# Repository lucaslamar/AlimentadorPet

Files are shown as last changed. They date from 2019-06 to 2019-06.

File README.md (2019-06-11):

# Alimentador Pet
o Alimentador Pet feito com Arduino, que é uma estrutura em que os donos podem usá-la para alimentar seus animais domésticos pelo celular via Bluetooth, onde este alcançar.

OBS: Trabalho para conclusão da materia: "Tópicos Avançados em Análise e Desenvolvimento de Sistemas(Arduino)" da Faculdade Projeção Sobradinho. Mudanças ou sugestões são bem vindas.

INTEGRANTES: 

<ul>
    <li>AQUILES DIAS
    <li> GABRIELLE LIMA FERREIRA
    <li> JHONNY CARVALHO ALVES
    <li> LUCAS LAMAR DA SILVA CARNEIRO
    <li> CAIO FERNANDO SILVA OLIVEIRA
</ul> <br />

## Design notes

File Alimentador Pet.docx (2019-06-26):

FACULDADE PROJEÇÃO

Tecnologia em Análise e Desenvolvimento de Sistemas

AQUILES DIAS DE SOUSA

CAIO FERNANDO SILVA OLIVEIRA

GABRIELLE LIMA FERREIRA

JHONNY CARVALHO ALVES

LEONARDO PEREIRA DA SILVA

LUCAS LAMAR DA SILVA CARNEIRO

ALIMENTADOR PET

Brasília, junho de 2019.

FACULDADE PROJEÇÃO

Tecnologia em Análise e Desenvolvimento de Sistemas

TEMA

Tópicos Avançados em Análise e Desenvolvimento de Sistemas apresentado ao Curso de Tecnologia em Análise e Desenvolvimento de Sistemas da Faculdade Projeção.

Brasília, ___ de __________ de [ano].

Banca Examinadora:

Professor(a) :[Informar o nome completo]

Orientador(a)

Professor(a) :[Informar o nome completo]

Professor(a) : [Informar o nome completo]

Professor Rosa Maria Diekn de Queiroz, Especialista

Coordenadora do curso de Sistemas de Informação

# LISTA DE ABREVIATURAS E SIGLAS

GND Ground

ABS Acrylonitrile Butadiene Styrene

SRAM Static Random Access Memory

EEPROM Electrically Erasable Programmable Read Only Memory

AWG American Wire Gauge

VDC Voltage Direct Current

AVR Automatic Voltage Regulator

PIC Peripherical Interface Controller

TTL Transistor-transistor logic

LED Light Emitting Diode

ISM Industrial Sientific and Medical

GFSK Gaussian Freguency Shift Keying

EMI Eletromagnetic Interference

# LISTA DE FIGURA

# LISTA DE TABELAS

# RESUMO

Este documento será relatado sobre o Alimentador Pet feito com Arduino, que é uma estrutura em que os donos podem usá-la para alimentar seus animais domésticos pelo celular via Bluetooth, onde este alcançar. Serão mostradas todas as etapas do desenvolvimento dele, como o objetivo, a descrição de cada item utilizado, cronograma, protótipos, entre outros.

Palavras-Chave: Alimentador Pet, Arduino.

# ABSTRACT

This document will be reported on the Pet Feeder made with Arduino, which is a framework in which owners can use it to feed their pets via their cell phone via Bluetooth wherever it reaches. It will show all the stages of its development, such as the objective, the description of each item used, schedule, prototypes, among others.

Keywords: Pet Feeder, Arduino.

# CAPÍTULO I

# VISÃO INICIAL

## 1. INTRODUÇÃO

Atualmente, a maioria das pessoas possui um animal de estimação (cães e gatos) em casa, onde elas cuidam e os alimentam diariamente, esses animais estão se tornando cada vez mais presente em todas as famílias. Atualmente no Brasil tem 52 milhões de cães e 22 milhões de gatos espalhados pelo país (IBGE, 2013). O Alimentador Pet feito com Arduino serve para deixar de forma mais simples e prática essa alimentação, pois o dono pode fazer isso automaticamente, usando um aplicativo no seu celular e assim a estrutura libera a ração para o seu animal comer. Dessa forma, o dono não precisa se preocupar com o horário, pois é só agendar no aplicativo a hora certa para alimentá-los, quando o celular estiver conectado via Bluetooth ele só irá precisar ativar para a ração cair.

O objetivo do projeto foi alcançado e o protótipo desenvolvido indicando que o Arduino pode ser utilizado para várias aplicações que podem simplificar tarefas quotidianas

## 2. Contextualização

O Arduino foi criado em 2005 e a busca por ele vem crescendo a cada dia. É uma plataforma de prototipagem (https://pt.wikipedia.org/wiki/Prot%C3%B3tipo) eletrônica de hardware livre (https://pt.wikipedia.org/wiki/Hardware_livre) e de placa única (https://pt.wikipedia.org/wiki/Computadores_de_placa_%C3%BAnica), é fácil de usar, tem baixo custo e pode ser levado a qualquer lugar devido ao seu tamanho ser pequeno. E ele pode ser usado para controlar e automatizar várias coisas.

Com essa facilidade no uso, o Alimentador Pet será feito com ele, para ser automatizado e tornar mais fácil para os donos a alimentação de seus animais domésticos.

## 3. Problemática

Alguns donos muitas vezes se esquecem de alimentar seu animal, pois estão ocupados fazendo outras coisas; e outros às vezes têm certa preguiça de ir e colocar a alimentação, assim o animal fica passando fome, podendo até adoecer.

## 4. Solução Proposta

Esse alimentador serve para ajudar o dono a alimentar o seu animal sem se preocupar em ir colocar a comida, podendo fazer isso automaticamente através de um aplicativo de celular.

## 5. Objetivo Geral

O objetivo geral é desenvolver um alimentador automático para animais de estimação utilizando o Arduino.

### 6. Objetivos Específicos

- Utilizar Arduino
- Mostrar detalhadamente cada ligação
- Mostrar a montagem passo a passo do projeto
- Criar estrutura.

# CAPÍTULO II

# METODOLOGIA APLICADA

## 1. Metodologia e Modelo de Desenvolvimento

A metodologia que será utilizada nesse projeto será a metodologia Ágil. A metodologia ágil é uma forma de acelerar as entregas durante o desenvolvimento de um projeto, fracionando o todo em entregas incrementais, trabalhando em times auto organizados e fazendo uso da Inteligência Coletiva, com equipes multidisciplinares, para atingir uma meta estabelecida a cada fase, até a conclusão final da entrega total do projeto.

## 2. Fundamentação teórica

- Arduino é uma plataforma de prototipagem eletrônica open source que se baseia em hardware e software flexíveis e fáceis de usar.
- Jumpers são condutores utilizados para conectar dois pontos de um circuito eletrônico.
- Protoboard de 830 pontos com ligações elétricas utilizada para montar circuitos eletrônicos sem precisar soldar os terminais, com um interruptor ao meio dela.
- Motor de passo é um tipo de motor elétrico usado quando algo tem que ser posicionado muito precisamente ou rodado de um ângulo exato.
- O módulo Relé é um módulo o qual torna realmente fácil conectar um relé a um Arduino. Ele já tem todos os componentes necessários para tal conexão, fazendo só com que você necessite conectar os cabos corretamente ao Arduino.
- O sensor de distância é um tipo de sensor que mede a distância entre um ponto de referência e um objeto desejado.
- Bluetooth é um protocolo de comunicação sem fio com baixo consumo de energia onde é possível fazer a transmissão de dados entre dispositivos. O alcance varia de 1 a 100 metros e o consumo de energia vai variar de acordo com a distância de comunicação (quanto maior a distância maior o consumo).
- A Minibomba de Água RS385 foi criada especialmente para o desenvolvimento de projetos de prototipagem, incluído automação residencial e protótipos robóticos baseados em plataformas microcontroladores, entre elas, Arduino e Raspberry Pi.
- O driver de motor de passo permite o Arduino controlar motores com correntes superiores a 50mA.
- A fonte de alimentação é um componente de aparelhos eletrônicos que tem como função transformar a energia elétrica que chega pelas tomadas em uma corrente elétrica contínua. Ou seja, ela recebe a energia em 110V ou 220V e transforma na voltagem adequada para o funcionamento do aparelho, que geralmente é 12V.

## 3. Montagem do Hardware

## 3. 1 Protótipo da Modelagem do Circuito

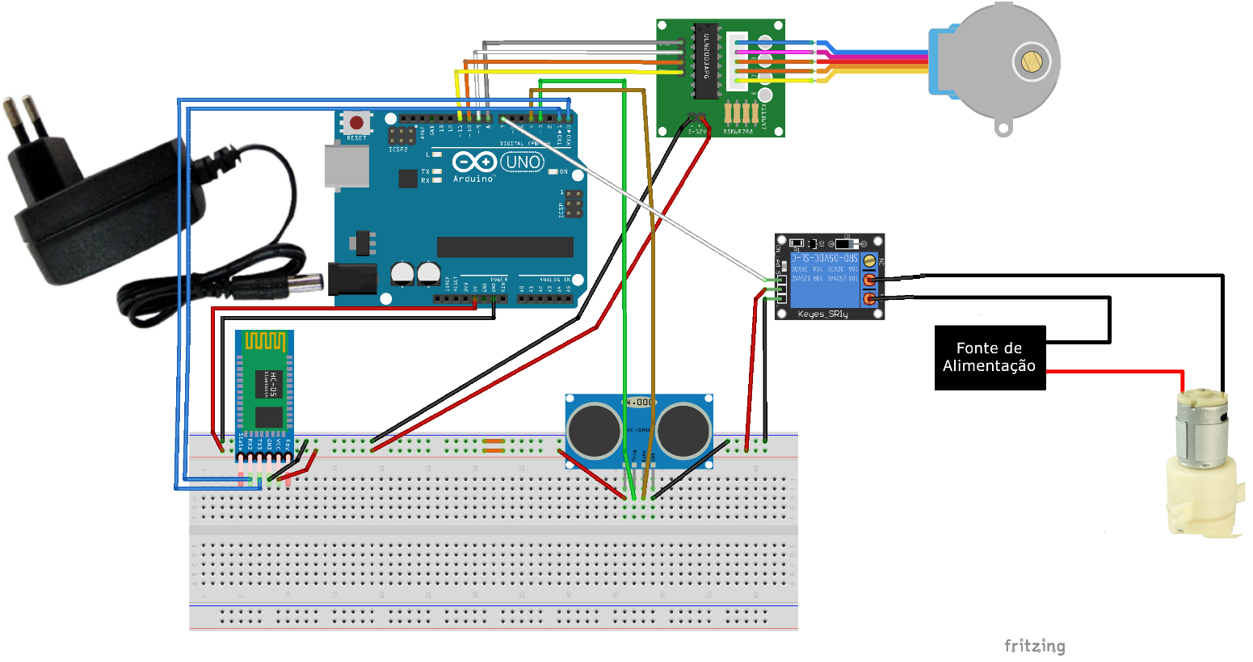
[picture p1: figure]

Figura 1 Modelagem do circuito

## 3.2 Especificação e Detalhamento dos itens utilizados

A placa Arduino costuma ser a primeira opção de muitos, ela seleciona automaticamente a fonte de alimentação (USB ou fonte externa). Ela se diferencia das outras por não utilizar o chip da FTDI USB-to-Serial. Ao invés deste chip, um Atmega8U2 já programado faz a função de converter os dados da USB para Serial.

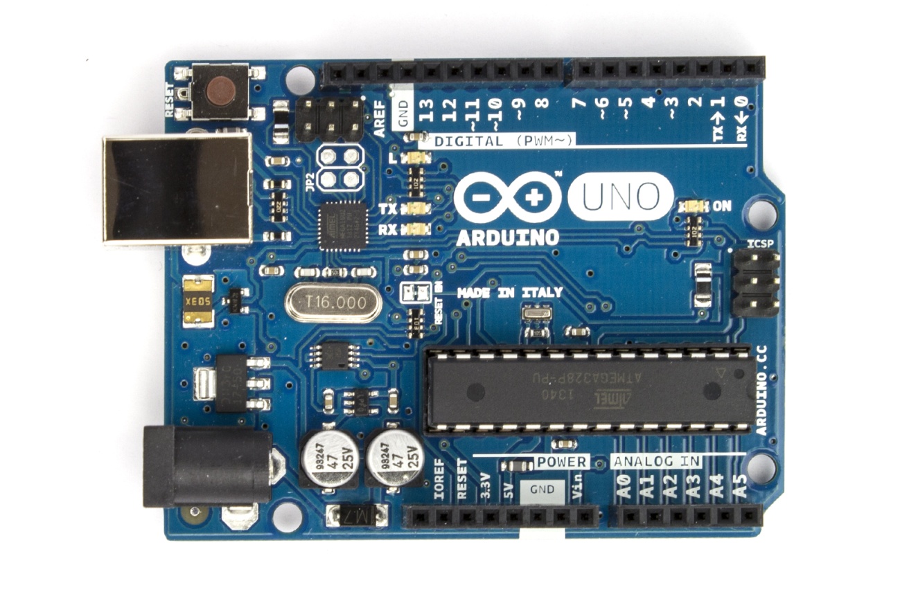
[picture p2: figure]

Figura 2 Placa Arduino Uno

- Microcontrolador: Atmega328
- Tensão de Operação: 5V
- Tensão de Entrada: 7-12V
- Portas Digitais: 14
- Portas Analógicas: 6
- Corrente Pinos I/O: 40mA
- Corrente Pinos 3,3V: 50mA
- Memória Flash: 32KB (0,5KB usado no bootloader)
- SRAM: 2KB
- EEPROM: 1KB
- Velocidade do Clock: 16MHz

Os Cabos Jumpers (https://www.curtocircuito.com.br/acessorios/cabos) são fios de ligação elétrica, ideais e indispensáveis para quem faz montagens com Placa Arduino (https://www.curtocircuito.com.br/arduino/placa-arduino), Protoboard (https://www.curtocircuito.com.br/acessorios/protoboard), Shield Arduino (https://www.curtocircuito.com.br/arduino/shield-arduino) e os mais diversos módulos (https://www.curtocircuito.com.br/modulos).

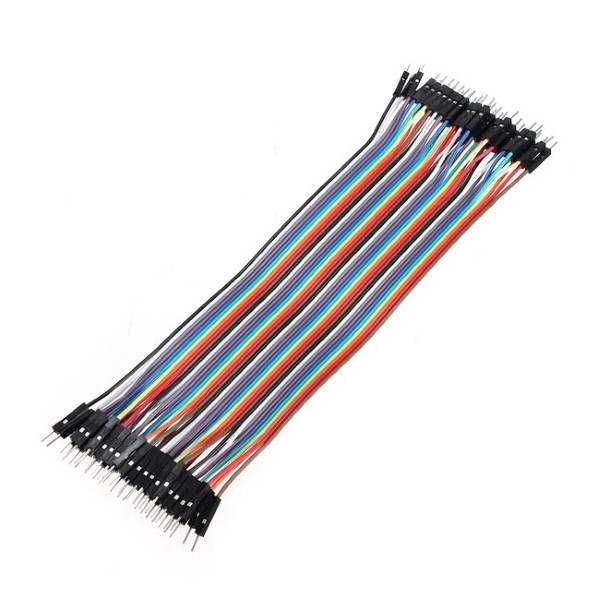
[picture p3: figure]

Figura 3 Jumpers

- Tipo: Macho x Macho
- Comprimento do Cabo: 20 cm
- Secção do condutor: 24 AWG (0,2 mm²)
- Condutores totalmente revestidos
- Diferenciado por 10 tipos de cores

A protoboard permite montar circuitos eletrônicos de forma simples já que não requer soldagem nos contatos, esta protoboard 830 pontos e ideal para quem procura algo simples e mais em conta.

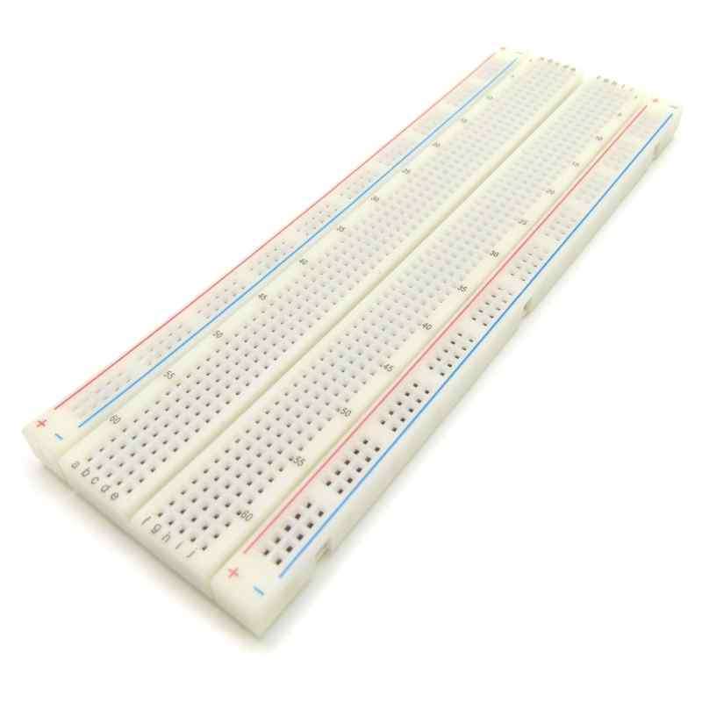
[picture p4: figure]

Figura 4 Protoboard

- 830 Furos
- Faixa de Temperatura: -20 a 80ºC
- Para terminais e condutores de 0,3 a 0,8 mm (20 a 29AWG)
- Resistência de isolamento: 100Mωmin.
- Tensão máxima: 500v AC por minuto
- Dimensões: 165mm x 57mm x 10mm
- Peso 70 gramas
- Material base: ABS

O motor de passo é um motor elétrico que desloca seu eixo um determinado ângulo a cada pulso recebido do drive de controle.

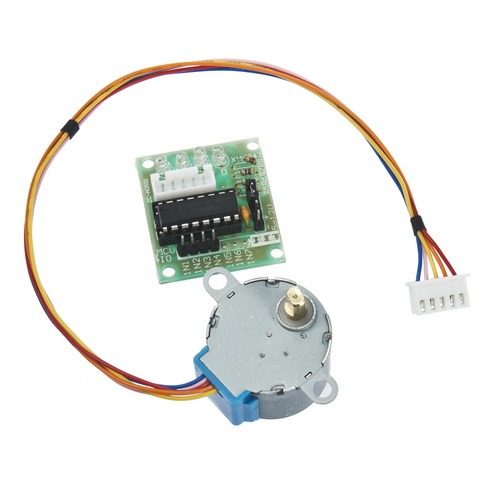
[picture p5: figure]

Figura 5 Motor de Passos

- Alimentação: 5v
- Fase: 4
- Ângulo do Passo: 5,625/64 ≈ 0,088°
- Redução: 1/64
- Resistência: 60 ohms/fase
- Torque Max: 2,2 Kgf.cm
- Diâmetro: 28mm
- Peso: 40g

A Fonte de Alimentação Chaveada 12V 2A é um produto muito utilizado na construção de projetos de automação residencial e na alimentação de pequenos circuitos, como, por exemplo, LEDS, câmeras de segurança, aparelhos eletroeletrônicos que exijam fontes com 12V e corrente de saída nominal de 2A, sendo projetadas para uso geral.

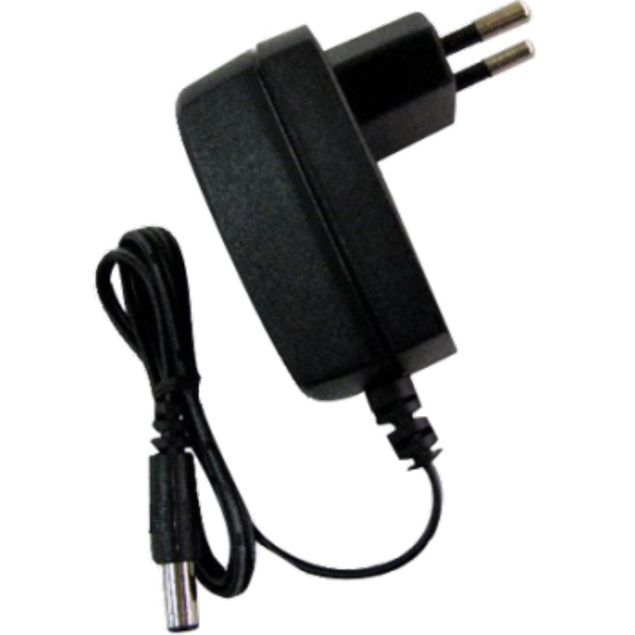
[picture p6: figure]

Figura 6 Fonte 12v A2

- Corrente máxima: 2 Amper
- Potência máxima: 12V
- Polaridade: Positiva no centro do Plug
- Proteção contra curto circuito
- Proteção contra aquecimento
- Frequência de operação de 47 a 64 Hz
- Peso: 118 g
- Largura: 8cm
- Tensão de saída: 12V (DC) 2A (2000mA);

Este Módulo Relé permite uma integração com uma ampla gama de microcontroladores como Arduino, AVR, PIC. A partir das saídas digitais pode-se, através do relé, controlar cargas maiores e dispositivos como motores AC ou DC, eletroímãs, solenoides e lâmpadas incandescentes.

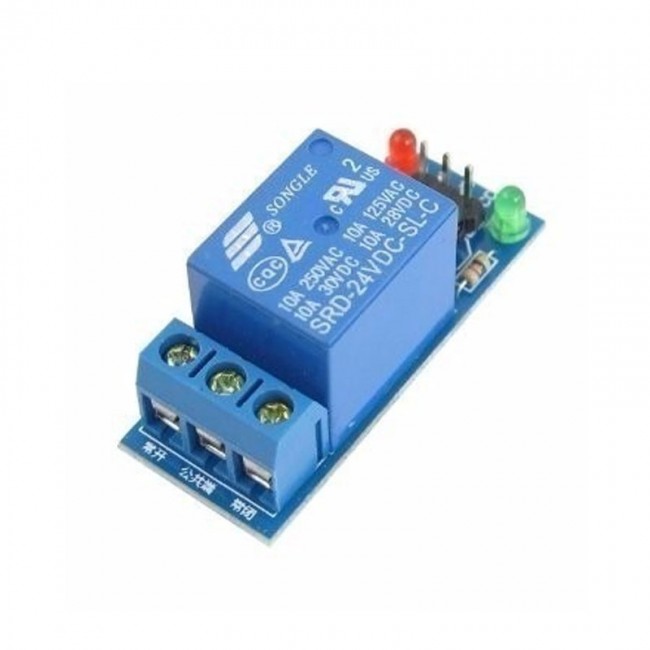
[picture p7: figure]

Figura 7 Modulo Relé

- Tensão de operação: 5V DC (VCC e GND)
- Tensão de sinal: TTL - 5V DC (IN)
- Corrente típica de operação: 15~20mA
- O relé possui contato NA e NF
- Capacidade do relé: 30 V DC e 10A ou 250V AC e 10A
- Tempo de resposta: 5~10ms
- Indicador LED de funcionamento
- Dimensões: 43mm (L) x 17mm (C) x 19mm (H)

O Sensor de Distância Ultrassônico HC-SR04 é capaz de medir distâncias de 2cm a 4m com ótima precisão.

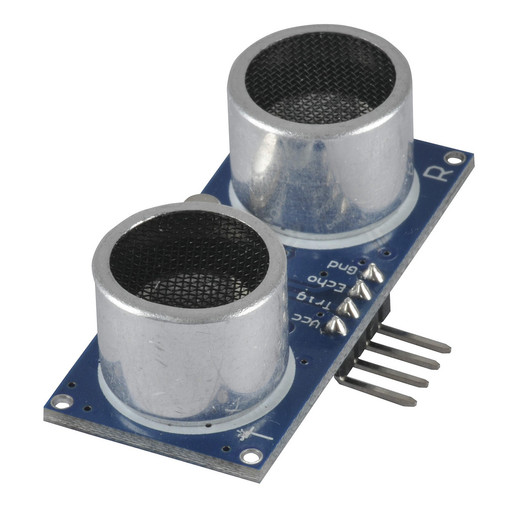
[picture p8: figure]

Figura 8 Modulo sensor ultrassónico HC-SR04

- Alimentação: 5V DC
- Corrente de Operação: 2mA
- Ângulo de efeito: 15°
- Alcance.: 2cm ~ 4m
- Precisão.: 3mm

O módulo Bluetooth HC-05 abstrai toda a parte da comunicação sem fio, bastando enviar os dados via comunicação serial para eles.

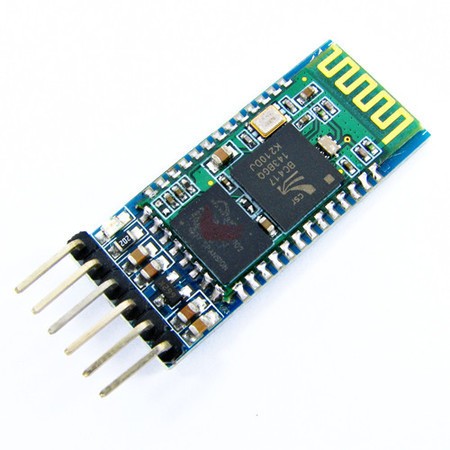
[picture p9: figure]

Figura 9 Módulo Bluetooth HC-05

- Protocolo Bluetooth: v1.1 / 2.0.
- Frequência: banda ISM de 2,4GHz
- Modulação: GFSK
- Potência de transmissão: menos de 4dBm Classe 2
- Sensibilidade: Menos de -84dBm no 0,1% BER
- Razão assíncrona: 2.1Mbps (Max) / 160 kbps
- Síncrono: 1Mbps / 1Mbps
- Porta serial Bluetooth (mestre e escravo)
- Alimentação 3,3VCC 50mA (suporta de 3,3 a 6V)
- Temperatura de operação: -5 a 45°C

Com um motor de tamanho adequado a Minibomba de Água RS385 é capaz de impulsionar entre 1500ml a 2000ml por minuto, sendo destacada pela sua eficiência e precisão durante sua execução em conjunto com o Arduino.

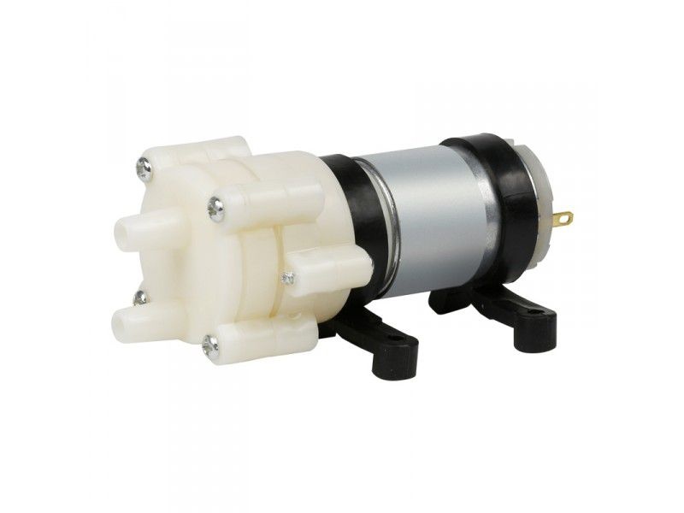
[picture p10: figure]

Figura 10 Minibomba de Água RS385

- Modelo: RS385;
- Materiais: metal e plástico;
- Tensão nominal: 12V;
- Voltagem adequada: DC 9 a 15V;
- Corrente sem carga: 0,6A;
- Corrente em máxima eficiência: ~2A;
- Altura de aspiração máxima: 2m;
- Elevação máxima: 3m;
- Vazão de água máxima: ~1,5 a 2 l/m;
- Diâmetro de entrada e saída: ~7,6mm;
- Diâmetro do motor: 28,6mm;
- Comprimento da bomba: 90mm;
- Peso: 100g.

O módulo controlador ULN2003 permite que, com o Arduino (que suporta corrente máxima de 50 mA por porta), sejam controlados motores que exijam correntes maiores, de até 500 mA. Este módulo aceita alimentação de 5 a 12 volts.

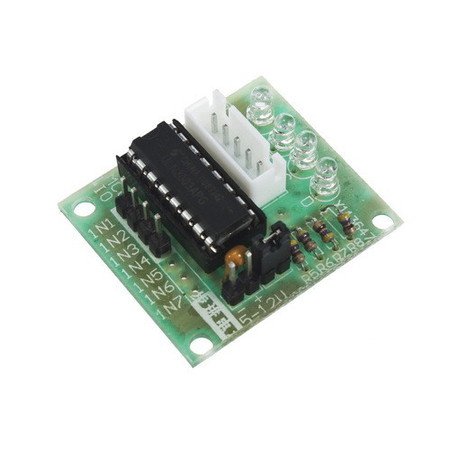
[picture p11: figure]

Figura 11 Driver

- Tensão nominal: DC 5V-12V Fase.
- Relação de redução: 1/64 Passo.
- Torque ângulo: 5,625 °/64 Resistência dc: 200w±7% (25 °)
- Resistência de isolamento:> 10M (500 v)
- Sem carga freqüência:> 600 Hz.
- Sem carga fora de freqüência:> 1000 Hz
- Torque:> 34.3mN.m (120 hz)
- Retenção de torque:> 34.3mN.m.

A fonte 12v possui proteção contra curto-circuito e sobrecarga, para prevenir os danos decorrentes de avarias elétricas, e contra sobretensão, para evitar ou minimizar problemas causados por descargas atmosféricas ou manobras da rede de distribuição elétrica.

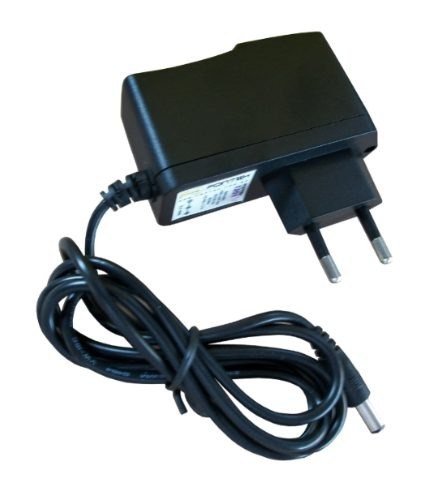
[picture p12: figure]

Figura 12 Fonte 12v

- Proteção contra curto-circuito na saída
- Contra sobrecarga
- Contra transientes na rede elétrica
- Contra ruídos na rede elétrica (RFI/EMI)
- Contra ruídos na carga (RFI/EMI)
- Isolação entrada / saída
- Peso: 0,90 Kg
- Largura: 8 cm
- Altura: 3 cm
- Profundidade: 4 cm

## 3.3 Detalhamento da comunicação entre os dispositivos

Os Jumpers vermelhos são conectados no 5v (positivos) da placa Arduino e na Protoboard.

Os Jumpers pretos são conectados no GND (negativo) da placa Arduino e na Protoboard.

O Primeiro Jumper azul conecta o RX do Bluetooth ao TX da placa Arduino.

O Segundo Jumper azul conecta o TX do Bluetooth ao RX da placa Arduino.

O Jumper verde conecta à porta 3 da placa Arduino no Trig do Módulo Sensor Ultrassónico.

O Jumper marrom conecta à porta 4 da placa Arduino no Echo do Módulo Sensor Ultrassónico.

O Jumper branco conecta à porta 7 da placa Arduino no Relé.

O Jumper cinza conecta à porta 8 da placa Arduino na entrada IN1 do Driver ULN2003.

O Jumper branco conecta à porta 9 da placa Arduino na entrada IN2 do Driver ULN2003.

O Jumper alaranjado conecta à porta 10 da placa Arduino na entrada IN3 do Driver ULN2003.

O Jumper amarelo conecta à porta 11 da placa Arduino na entrada IN4 do Driver ULN2003.

O motor de passo e conectado no Driver ULN2003 com a cor azul em cima.

O fio positivo da fonte 12v conecta no positivo da Minibomba d’agua RS385.

O fio negativo da fonte 12v conecta no NO do Relé.

O jumper preto conecta o negativo da Minibomba d’agua RS385 no COM do Relé.

## 4. Desenvolvimento do software

A linguagem utilizada nesse projeto em Arduino foi a C++, é uma linguagem de programação compilada (https://pt.wikipedia.org/wiki/Linguagem_de_programa%C3%A7%C3%A3o_compilada) multi-paradigma (https://pt.wikipedia.org/wiki/Paradigma_de_programa%C3%A7%C3%A3o) (seu suporte inclui linguagem imperativa (https://pt.wikipedia.org/wiki/Programa%C3%A7%C3%A3o_imperativa), orientada a objetos (https://pt.wikipedia.org/wiki/Programa%C3%A7%C3%A3o_orientada_a_objetos) e genérica (https://pt.wikipedia.org/wiki/Programa%C3%A7%C3%A3o_gen%C3%A9rica)) e de uso geral. É uma linguagem tradicional bastante conhecida pelos programadores, foi desenvolvida por Bjarne Stroustrup dos Bell Labs na década de 80 com o objetivo de melhorar a linguagem de programação C, o C++ é uma linguagem extensível já que podemos definir novos tipos de tal maneira que eles agem de mesmo modo que os tipos pré-definidos que fazem parte da linguagem padrão.

## 5. Imagens das fases de montagem do protótipo

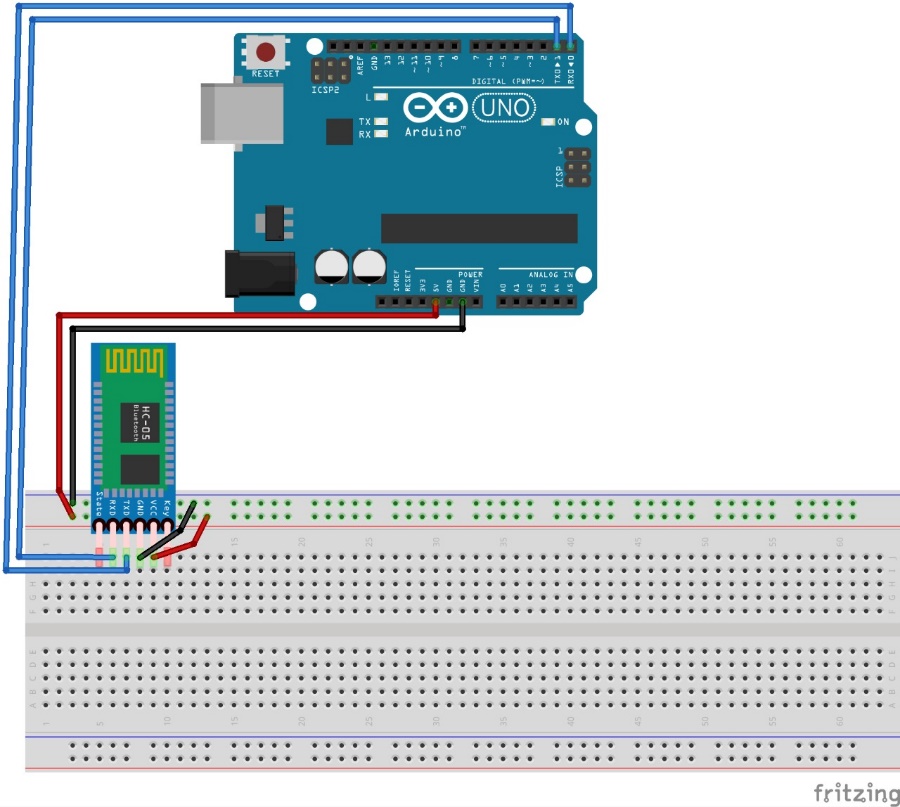
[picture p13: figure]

Figura 13 Montando o Bluetooth

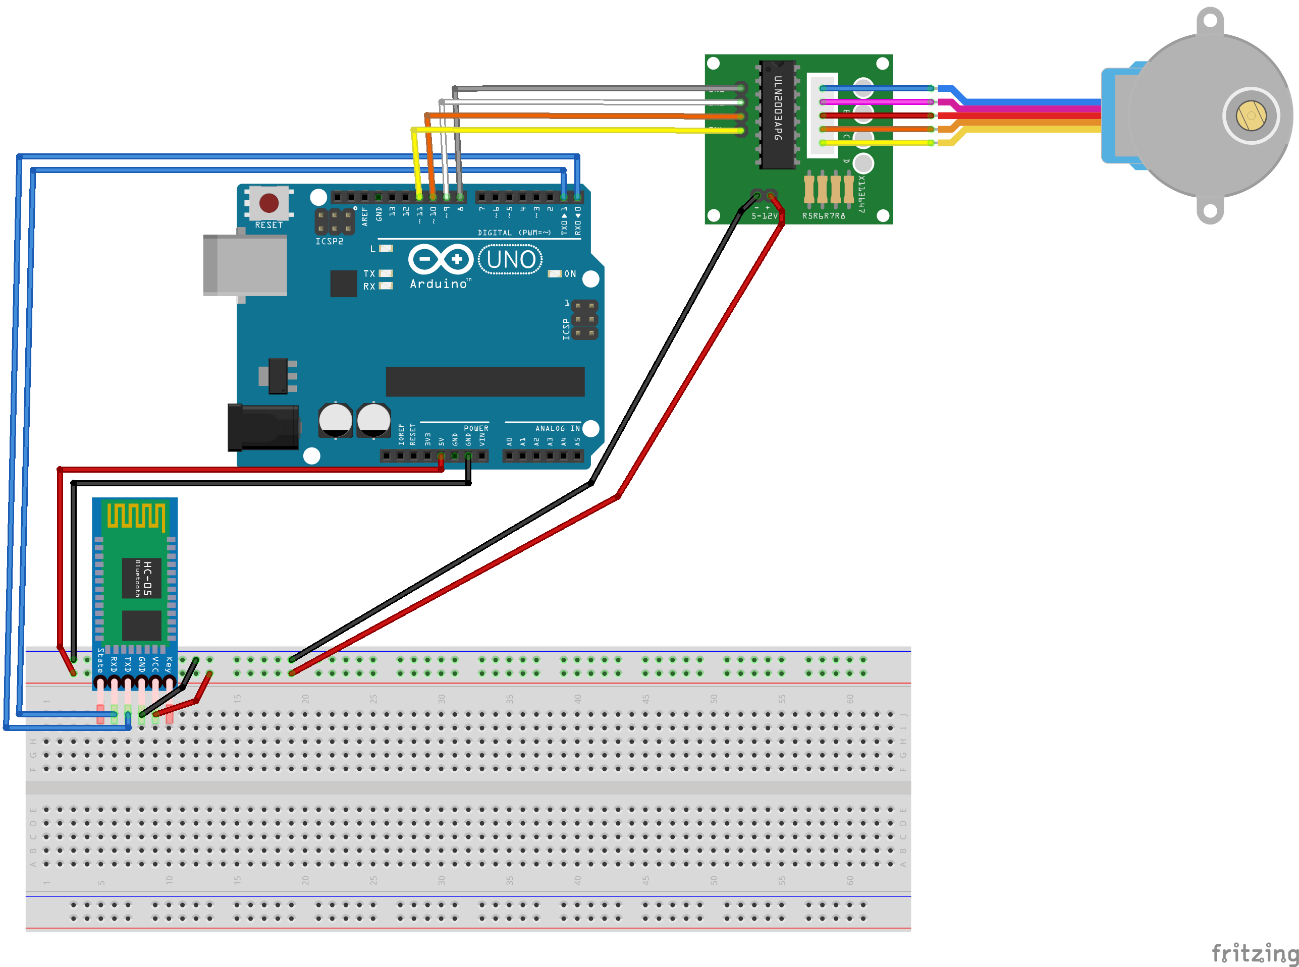
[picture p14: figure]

Figura 14 Montando o Bluetooth e o Motor de Passos

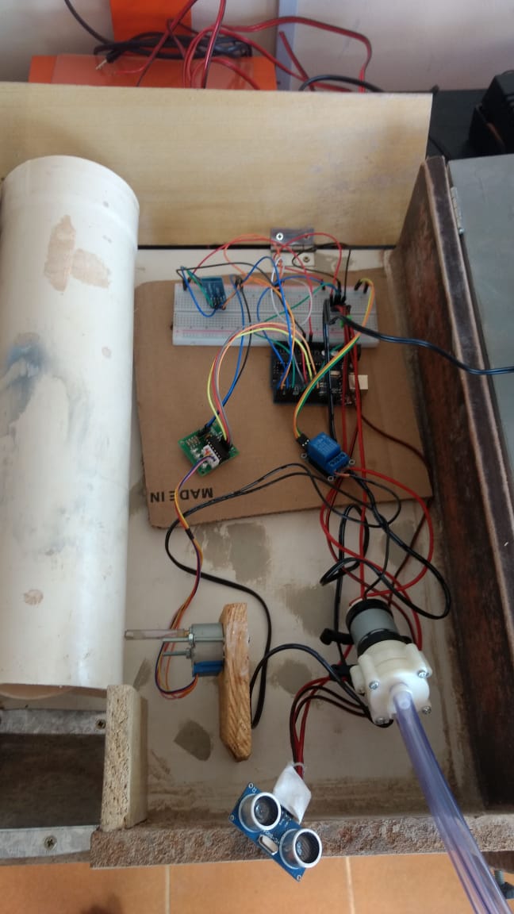
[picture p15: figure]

Figura 15 Projeto Completo

## 6. Cronograma

Tabela 1 Cronograma de Desenvolvimento do Alimentador

| 2018
FASES DO PROJETO | Fev | Mar | Abr | Mai | Jun | Jul | Ago | Set | Out | Nov | Dez
Levantamento dos equipamentos necessários | | | X
Compra dos equipamentos | | | | X
Programação | | | | X
Documentação | | | | | X

# 7. CONCLUSÃO

A automação bem como os cuidados com os pets vem se tornando de extrema importância com isso o alimentador pet cumpri o que promete alimentar seu pet de forma automatizada. Todavia este aqui apresentado não passa de um protótipo sinta-se à vontade para achar uma solução melhor e mais pratica caso necessário

A principal vantagem deste projeto em relação aos alimentadores existentes no mercado é o fato de que o mesmo não está limitado a liberar comida apenas de tempos em tempos. O alimentador proporciona a liberdade ao usuário de escolher a quantidade de refeições e os respectivos horários de liberação de alimento, não tendo a necessidade de seguir intervalos lógicos ou mesmo respeitar horários inteiros, dando assim total comodidade ao usuário.

# Referências

Filipeflop, 2019. Disponivel em: <https://www.filipeflop.com/produto/modulo-bluetooth-rs232-hc-05/>.

Filipeflop, 2019. Disponivel em: <https://www.filipeflop.com/produto/motor-de-passo-driver-uln2003-arduino/>.

Fronteira Tec, 2019. Disponivel em: <http://fronteiratec.com/blog/protoboard-para-que-serve-e-como-utiliza-lo/>.

Multilógica-Shop, 2019. Disponivel em: <https://multilogica-shop.com/modulo-bluetooth-hc-05>.

Robson Camargo, 2019. Disponivel em: <https://robsoncamargo.com.br/blog/o-que-e-metodologia-agil>.

Tec Tudo, 2019. Disponivel em: <https://www.techtudo.com.br/noticias/noticia/2015/03/jumpers-entenda-o-que-sao-e-para-que-servem-essas-pecas.html>.

Baú da Eletronica, 2019. Disponivel em: <http://www.baudaeletronica.com.br/modulo-rele-5v.html>.

MONK, S. 30 Projetos Com Arduino, 2014.

MONK, S. Movimento, luz e som com Arduino e Raspberry Pi, 2016.

MONK, S. Programação com Arduino Começando com Sketches, 2017.

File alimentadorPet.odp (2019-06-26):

## Alimentador Pet

## Objetivo

- O objetivo do nosso projeto foi criar o Alimentador Pet;


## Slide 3

Como surgiu essa ideia?

## Dificuldades

- Programação;
- Montagem da estrutura;
- Ligações

## Materiais

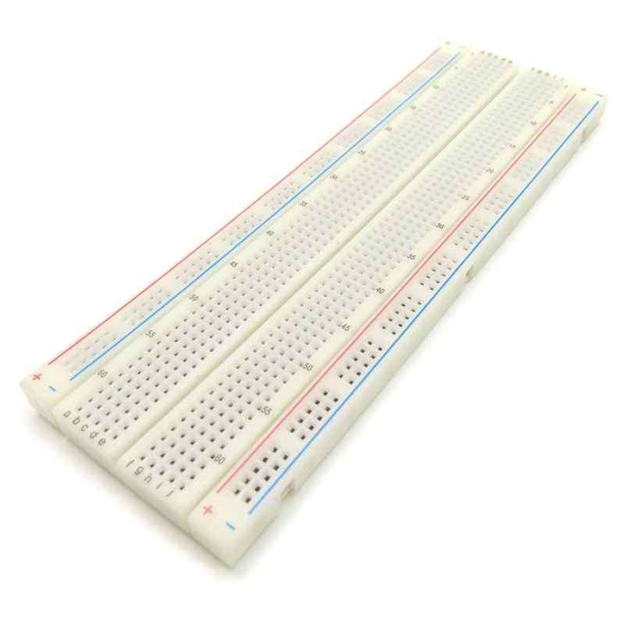
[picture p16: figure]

Protoboard 830 pontos

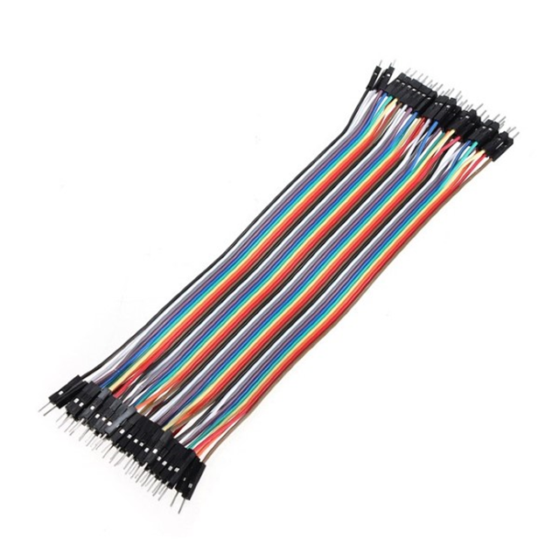
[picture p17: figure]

Jumpers

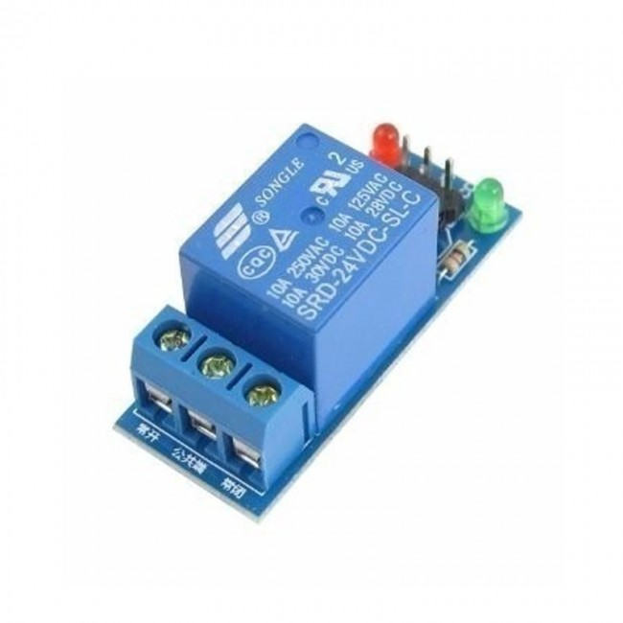
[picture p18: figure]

Relé 5v

- Arduino Uno

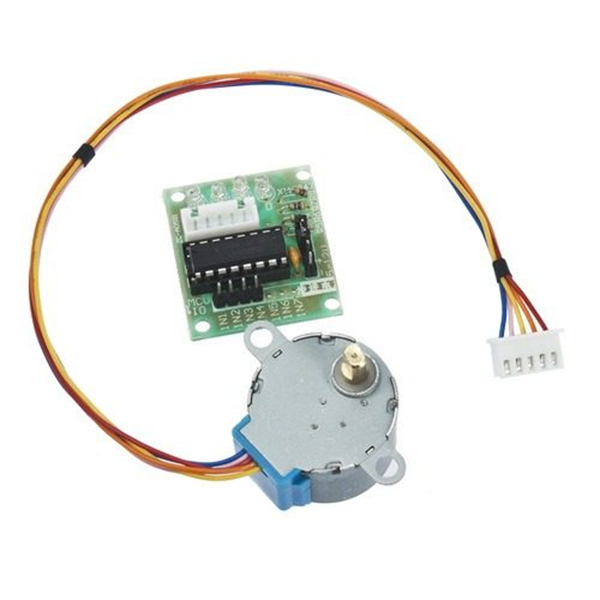
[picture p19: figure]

Motor de passos

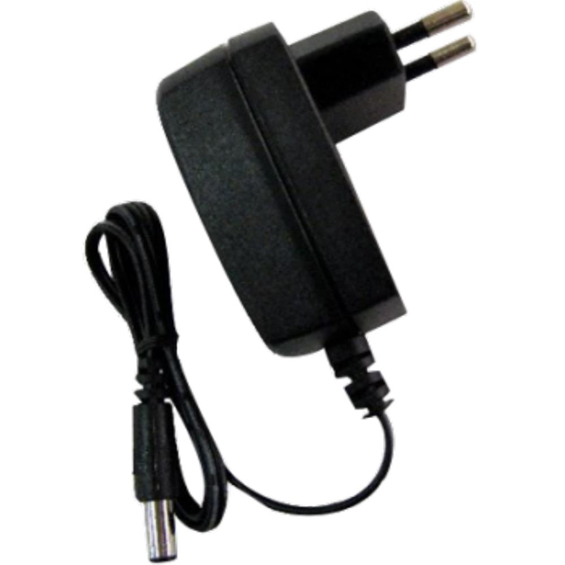
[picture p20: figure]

Fonte 12v

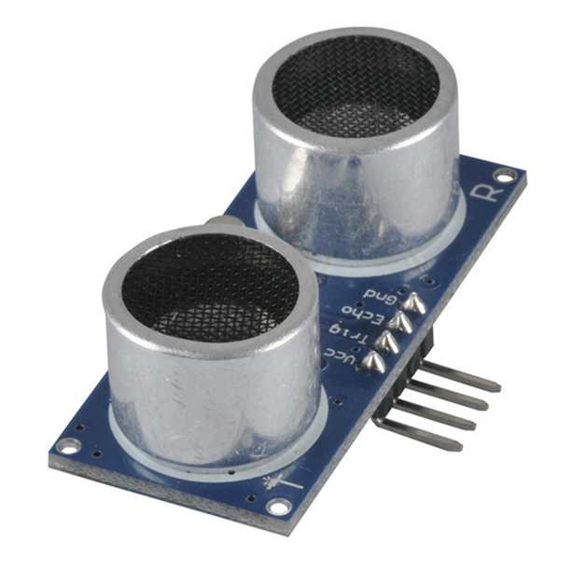
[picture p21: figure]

Sensor Ultrassônico

HC-SR04

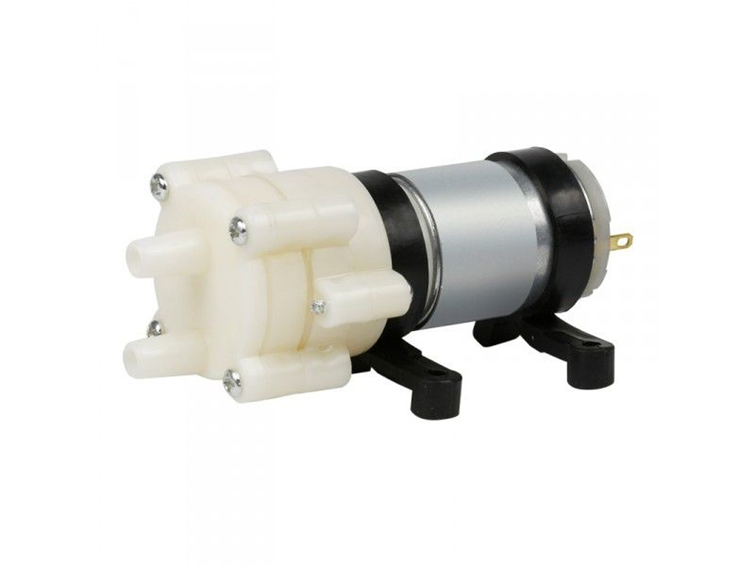
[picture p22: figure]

Mini Bomba d’agua

RS 385

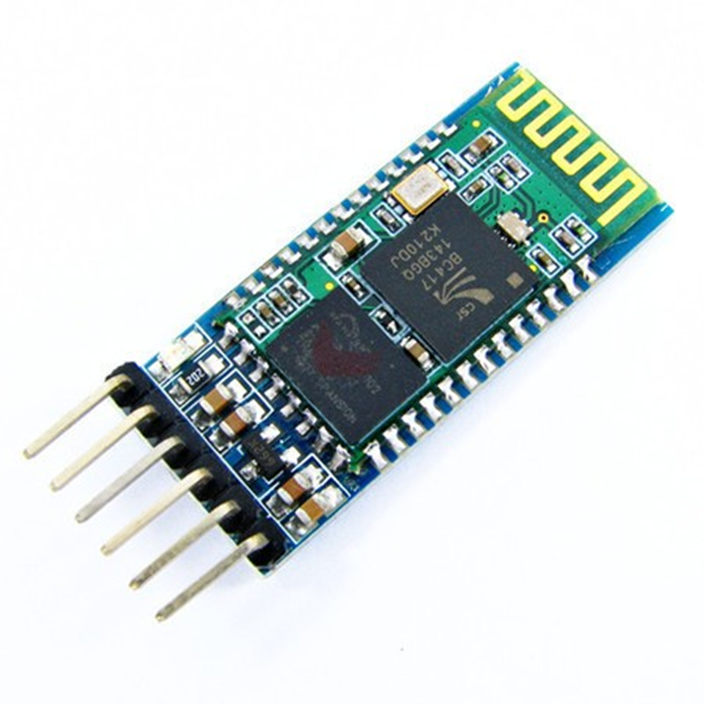
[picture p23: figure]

Bluetooth HC-05

## Circuito

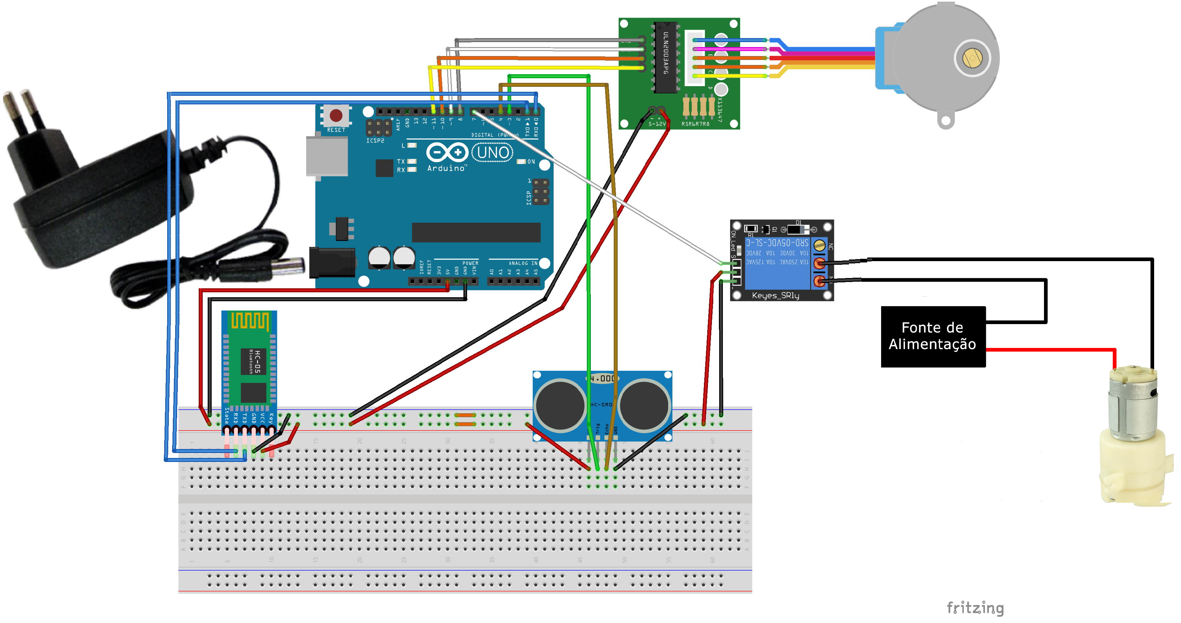
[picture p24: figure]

## Planejamento

- Procurar saber o que seria utilizado no projeto;
- Baixo Custo;
- Simplicidade;
- Possibilidade de evolução;
- Mercado;

## Linguagens/Persistência Utilizada

- C++;
- Arduino;

## Resultado Obtido

- Foi conseguir concluir o projeto Alimentador Pet;

## Conclusão

- Nosso maior desafio nesse projeto foi aprender a trabalhar em equipe;
- Ter perseverança e nunca desistir;
- E estamos bastante satisfeito com os objetivos alcançados;

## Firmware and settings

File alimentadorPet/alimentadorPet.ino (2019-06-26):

// bibliotecas
#include <Stepper.h> 

// --- Mapeamento de Hardware ---
#define led         13                             //led onboard
#define bomba        7                             //Pino de controle da bomba d'água
  #define echo       3                            //Pino de echo do HC-SR04
#define trig         4                         //Pino de trigger do HC-SR04
const int stepsPerRevolution = 500;

Stepper myStepper(stepsPerRevolution, 8,10,9,11); //Inicializa a biblioteca utilizando as portas de 3 a 6 para  ligacao ao motor 

// --- Constantes ---
#define full_sec     3                           //tempo para encher recipiente (em segundos)
 

// --- Protótipo das Funções Auxiliares ---
float measureDistance();                      //Função para medir, calcular e retornar a distância em cm
void trigPulse();                             //Função que gera o pulso de trigger de 10µs


// --- Variáveis Globais ---
 
boolean water;                                //Verdadeiro para objetos detectador por mais de 2 segundos
boolean control_end;                          //Indicação de processo concluído
float dist_cm;                                //Armazena a distância em centímetros entre o robô e o obstáculo
short counter = 0x00;                         //Contador auxiliar para interrupção
short test_Object = 0x00;                     //Verifica se haverá um objeto de fato
short seconds = 0x00;                         //Tempo de operação da bomba em segundos
int data = 0;


// --- Rotina de Interrupção ---
ISR(TIMER2_OVF_vect)
{
    TCNT2=100;                            //Reinicializa o registrador do Timer2
    counter++;                            //Incrementa counter
    
    
    // -- Base de tempo de 1 segundo --
    if(counter == 0x64)                   //counter igual a 100d?
    {                                     //Sim...
        counter = 0x00;                   //Reinicia
        test_Object++;                    //incrementa variável de teste
        
        if(test_Object == 0x02)           //test_Object igual a 2?
        {                                 //Sim...
            test_Object = 0x00;           //Reinicia
            water       = 0x01;           //seta variável de detecção
                   
        
        } //end if test_Object
        
        
        if(water)                         //variável de detecção de objeto setada?
        {                                 //Sim...
           seconds++;                     //incrementa os segundos
           digitalWrite(bomba, HIGH);     //liga bomba
           
           if(seconds == full_sec)        //atingiu o tempo para encher recipiente?
           {                              //Sim...
               digitalWrite(bomba, LOW);  //desliga bomba
               seconds = 0x00;            //reinicia segundos
               water   = 0x00;            //limpa water
               TIMSK2  = 0x00;            //desabilita interrupção do timer2
               control_end = 0x01;        //seta control_end 
                
           }  //end if seconds
           
           
        } //end if water
    
    
        digitalWrite(10, !digitalRead(10));   //Inverte o estado da saída (teste da base de tempo)
    
    
    } //end if counter
    
    
    
} //end ISR


// --- Configurações Iniciais ---
void setup()
{
  // -- Configuração de Entradas e Saídas --
     pinMode(10,    OUTPUT);
     pinMode(led,   OUTPUT);
     pinMode(bomba, OUTPUT);
     pinMode(trig,  OUTPUT);
     pinMode(echo,   INPUT);
     myStepper.setSpeed(60); //Determina a velocidade inicial do motor 
     Serial.begin(9600);
     
     
/*     
    Cálculo do estouro do Timer2

        Estouro = (256 - TCNT2) x prescaler x ciclo de máquina
       
        Ciclo de máquina = 1/Fosc = 1/16E6 = 62,5ns = 62,5E-9s
       
        Estouro = (256 - 100) x 1024 x 62,5E-9 = 9,98ms 
*/     

  // -- Configuração dos registradores do Atmega 328p --
     TCCR2A = 0x00;   //Timer operando em modo normal
     TCCR2B = 0x07;   //Prescaler 1:1024
     TCNT2  = 100;    //10 ms overflow again
     TIMSK2 = 0x00;   //Interrupção desabilitada inicialmente
     
  // -- Inicialização de variáveis e I/Os --
     digitalWrite(bomba, LOW);   //bomba inicia desligada
     water  = 0x00;              //detecção de objeto inicia falsa
     control_end = 0x00;         //limpa control_end
 
 
} //end setup
 

// --- Loop Infinito ---
void loop()
{
   
  myStepper.step(0); // motor parado
   dist_cm = measureDistance();               //Atualiza distância em centímetros
   
   
   if(dist_cm < 0x06 && !control_end)         //Distância menor que 6cm e control_end limpa?
   {                                          //Sim...
       
       TIMSK2 = 0x01;                         //Habilita interrupção do Timer2
       digitalWrite(led, HIGH);               //liga LED
   
   } //end if
   
   else                                       //Senão...
   {
       
       TIMSK2 = 0x00;                         //Desabilita interrupção do Timer2
       digitalWrite(led, LOW);                //desliga LED
       test_Object = 0x00;                    //Reinicia test_Object
       if(dist_cm > 0xA) control_end = 0x00;  //Limpa control_end
   
   } //end else
   
   delay(65);                                //Leituras a cada 65 ms


   
  if(Serial.available() > 0)
  {
    Serial.print("1: 600");
    Serial.print("2: 800");
    Serial.print("3: 1200"); 
    
    data = Serial.read();
    Serial.print(data);
    Serial.print("\n");

    if(data == '1')
    {
      myStepper.step(600);
    }
    else if(data == '2')
    {
       myStepper.step(800);
    }

   else if(data == '3')
    {
       myStepper.step(1200);
    }

  }
} //end loop



// --- Desenvolvimento das Funções Auxiliares ---


float measureDistance()                       //Função que retorna a distância em centímetros
{
  float pulse;                                //Armazena o valor de tempo em µs que o pino echo fica em nível alto
        
  trigPulse();                                //Envia pulso de 10µs para o pino de trigger do sensor
  
  pulse = pulseIn(echo, HIGH);                //Mede o tempo em que echo fica em nível alto e armazena na variável pulse
    
  /*
    >>> Cálculo da Conversão de µs para cm:
    
   Velocidade do som = 340 m/s = 34000 cm/s
   
   1 segundo = 1000000 micro segundos
   
      1000000 µs - 34000 cm/s
            X µs - 1 cm
            
                  1E6
            X = ------- = 29.41
                 34000
                 
    Para compensar o ECHO (ida e volta do ultrassom) multiplica-se por 2
    
    X' = 29.41 x 2 = 58.82
 
  */
  
  return (pulse/58.82);                      //Calcula distância em centímetros e retorna o valor
  
  
} //end measureDistante


void trigPulse()                             //Função para gerar o pulso de trigger para o sensor HC-SR04
{
   digitalWrite(trig,HIGH);                  //Saída de trigger em nível alto
   delayMicroseconds(10);                    //Por 10µs ...
   digitalWrite(trig,LOW);                   //Saída de trigger volta a nível baixo

} //end trigPulse

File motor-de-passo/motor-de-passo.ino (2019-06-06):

#include <Stepper.h> 
 
const int stepsPerRevolution = 500; 
  
//Inicializa a biblioteca utilizando as portas de 8 a 11 para 
//ligacao ao motor 
Stepper myStepper(stepsPerRevolution, 8,10,9,11); 
  
void setup() 
{ 
 //Determina a velocidade inicial do motor 
 myStepper.setSpeed(60);
} 
  
void loop() 
{ 

 //Gira o motor no sentido anti-horario a 120 graus
 myStepper.step(600); 

}

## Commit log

2019-04-29 Codico do motor de passo
2019-05-15 alimentador quase pronto
    [montagemBluetooth.fzz]
2019-05-29 quase la - testar
